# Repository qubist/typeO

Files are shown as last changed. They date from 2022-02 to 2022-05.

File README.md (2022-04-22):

# typeO

e-paper typing software and hardware

## Background

For now, this repo is for collecting relevant information for the prototyping of the typeO using a remarkable and a keyboard.

## Pogo pin connector

The pogo pin connector is in prototype stage. The goal of this device is to provide keyboard access to the reMarkable 2 through the Pogo pins, which have OTG support (unlike the USB C port).

### Software

See [pogo-pin-software.md](/pogo-pin-software.md)

### Hardware

#### Prototype:

https://www.youtube.com/watch?v=7q5tBEi4npA

#### Parts list

- Pogo pin header:
   - Straight: https://www.digikey.com/en/products/detail/821-22-005-10-001101/ED8198-05-ND/1146577?itemSeq=360991255
   - Right-angle: https://www.digikey.com/en/products/detail/mill-max-manufacturing-corp/829-22-005-20-001101/2416226
   - Long: https://www.digikey.com/en/products/detail/mill-max-manufacturing-corp/816-22-005-10-003101/6149711
- USB C breakout: https://www.digikey.com/en/products/detail/4090/1528-2873-ND/9951930?itemSeq=360991872
- 5.1 kOhm resistor
- 1/8in x 1/2in magnets: https://www.kjmagnetics.com/proddetail.asp?prod=D28-N52&cat=168
- tiny dip switch on the PCB for hackability: https://www.digikey.com/en/products/detail/e-switch/KAE01SGGT/3749638

#### Circuit

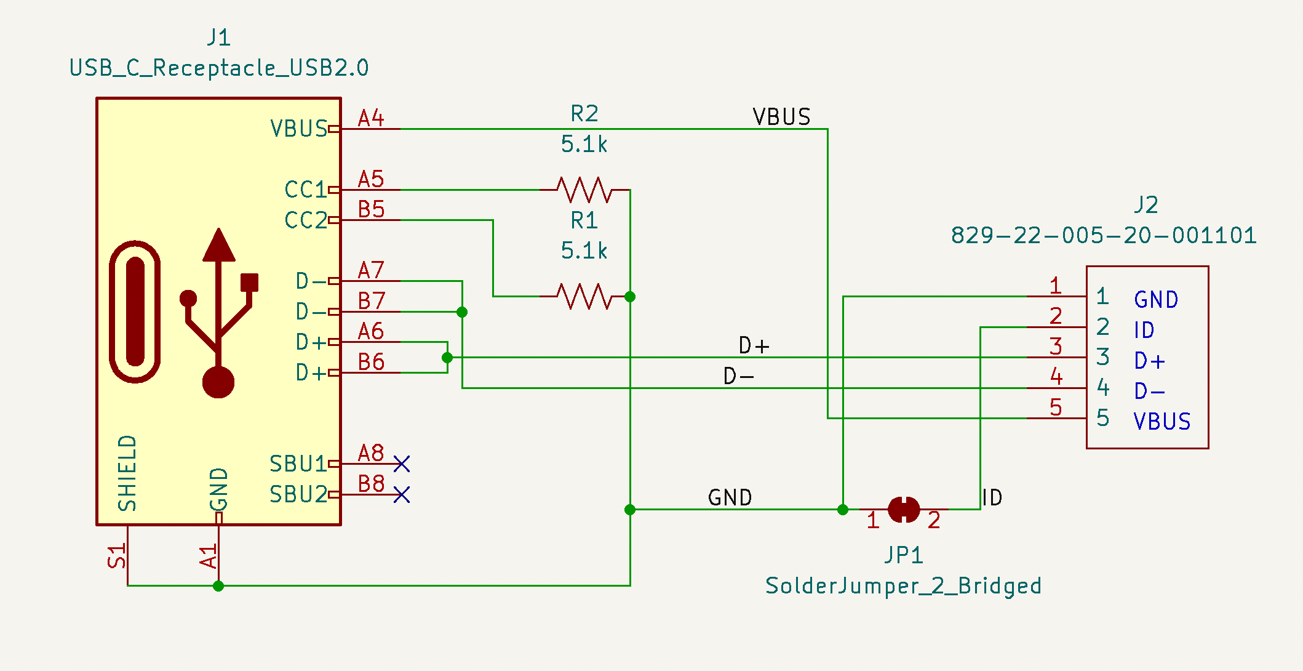
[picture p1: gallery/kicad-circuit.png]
Circuit diagram


Layout image

[Prototype circuit diagram](pcb/prototype_circuit.fzz)

([Reference USB-C pinout](https://electronics.stackexchange.com/questions/291413/usb-c-to-usb-a-pinout/291427))

#### 3D printed part

The 3D printed part holds the magnets and pogo pin headers together and friction fits onto the remarkable. The magnets and flange help it align, and the pins should contact.

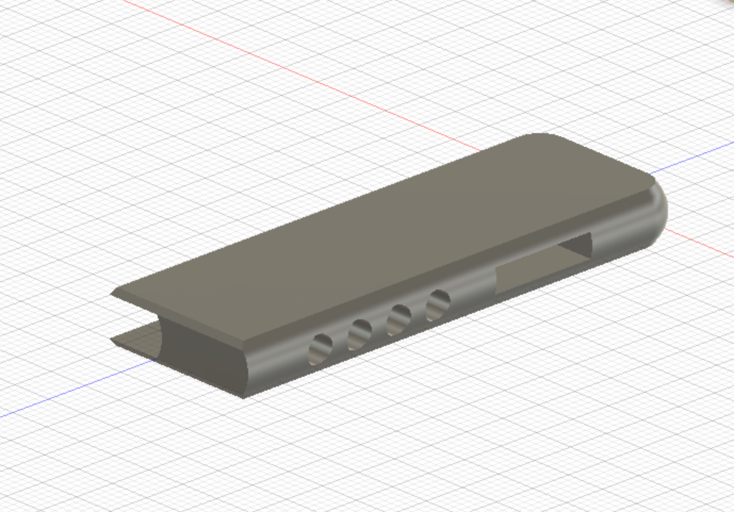
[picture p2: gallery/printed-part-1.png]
printed part 1

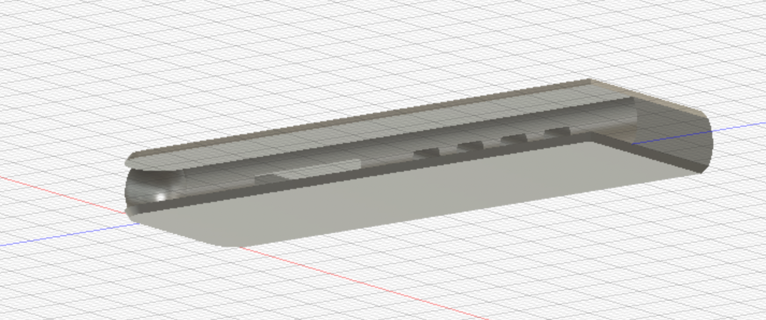
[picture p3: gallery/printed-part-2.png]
printed part 2


## Future

[Feature wishlist](/feature-wishlist.md)

## Other resources

[See also link collection](/sick-links.md)

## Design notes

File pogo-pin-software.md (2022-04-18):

# Pogo behavior and software overview

## Summary

- USB-C port is not powered, works with USB-OTG if externally powered, and requires enabling in software.
- Pogo pins are powered only if USB-C is plugged in, works with USB-OTG if enabled in software, and ID pin grounded.
    - "UPDATE: It seems like you need to have it plugged in to initially work, but after you do the initial fix, it works without plugging it in." (https://github.com/dps/remarkable-keywriter/issues/14#issuecomment-758293624)
- If you wanna use a keyboard, the command `echo 2 > /sys/otgcontrol/control/otg1_controllermode` needs to be run on every reboot to get OTG to work. This can be done automatically. It also seems like it might need to be plugged in to power by USB-C when this command is run for it to work.
    - Here's someone who set up this (or equivalent) command to run automatically: https://benkku.medium.com/the-remarkable-2-tablet-as-a-coding-writing-device-3981570343e2 (search for `Automatically turn on USB-On-the-Go / Host Mode`)

## Always enable OTG keyboard:

Create a file `/usr/local/sbin/disableotg.sh`
```sh
#! /bin/sh
echo 2 > /sys/otgcontrol/control/otg1_controllermode
```
Edit the table of cronjobs: `crontab -e`:
- Add the line disabling OTG-auth recurring at reboot 
  ``` @reboot /usr/local/sbin/diableotg.sh >/dev/null 2>&1```.
Reboot to get it running or run the script yourself.

---

## From the Wiki

The remarkable 2 has two USB port, one USB-C port used for charging and connecting to a PC and a second one exposed on the pogo pins.
The chip used for charging the device (max77818) only supports one VBUS with back power. This bus is connected to the pogo pins, so only this port can be used for USB OTG.

=== Pogo Pins OTG ===

The pogo pinout is:

    (left to right)  
    
    GND, ID, D+, D-, VBUS

With the VBUS closest to the USB-C port. There is a custom linux drivers that controls the USB port dr mode and VBUS power ([[https://github.com/reMarkable/linux/tree/zero-sugar/drivers/misc/rm-otgcontrol]]). The driver monitors the status of the ID pin. If it gets grounded it tries to authenticate the device before changing the port to OTG mode. This authentication is intended to work over a one-wire protocol over the ID port, but is currently unimplemented. As a result the device detection is currently disabled by default ([[https://github.com/reMarkable/linux/commit/e27d817e3c968624f7ae454f9b643157a2d39dab]]).

Luckily there is an unauthenticated mode that can be enabled by writing to sysfs:

    echo 2 > /sys/otgcontrol/control/otg1_controllermode

Now whenever the ID pin is connected to ground, the VBUS supply will be set to OTG mode and the USB mode will change to host. This allows connecting any OTG device by connecting the pogo pins to a Micro-USB connector and using an OTG cable (or creating a custom pogo cable that connects ID to ground).

SOURCE: https://remarkablewiki.com/tech/rm2_otg_pogo

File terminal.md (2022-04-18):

Using Terminal on reMarkable
============================

Prompt
------

### Add battery percentage to the prompt

```
# Show battery percentage in prompt
function battery {
    rot power get batteryLevel
}
PS1='\u@\H:\w ($(battery)%) $ '
```

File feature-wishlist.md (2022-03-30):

# Feature wishlist

## Core features
 
### Hardware

* e-paper screen
* Really lithe casing, Like, a beautiful wooden clamshell kind of thing. Smooth. And grabwanty. Lightweight, durable
* 1 USB-C port for charging and BYO keyboard
* 1 POGO (?) connection for an optional keyboard attachment/case
* Optional keyboard attachment/case
* Open source hardware
* Repairable / hackable
* Expandable storage

### Software

* Fast responsive typing
* Moving cursor around
* Selecting
* Exporting files to a computer
* Open source

## Would be awesome

* warm backlight
* ipx8, I want submerssability, Salty finger beach collaboration
* collaborative editing out in the sun, bust feeling ever
* Vim mode

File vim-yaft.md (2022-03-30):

# Using Vim on Yaft

## Setup

1. Install Yaft
2. Add this to `~/.bashrc`: `export TERM=xterm`

Done.

## Tips

* Hold the escape button on the on-screen keyboard to hide the keyboard
* You can use git to get your vim config from GitHub:
  * `opkg install git`
  * `opkg install git-https`
  *  `git clone ...`
  * `unset LD_PRELOAD` to remove annoying message
* Keep unessesary movement/animation to a minimum
  * Turn of relative line numbers in the gutter

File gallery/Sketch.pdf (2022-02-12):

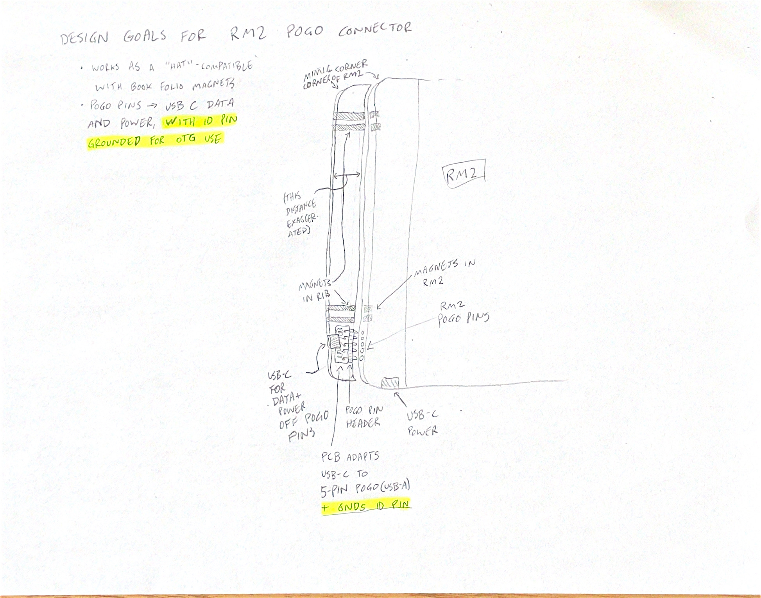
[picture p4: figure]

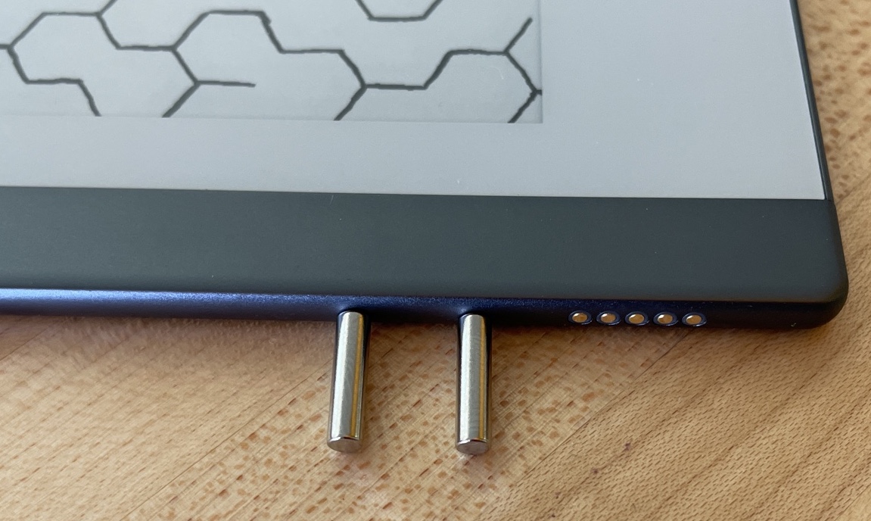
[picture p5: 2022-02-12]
gallery/magnets.jpeg

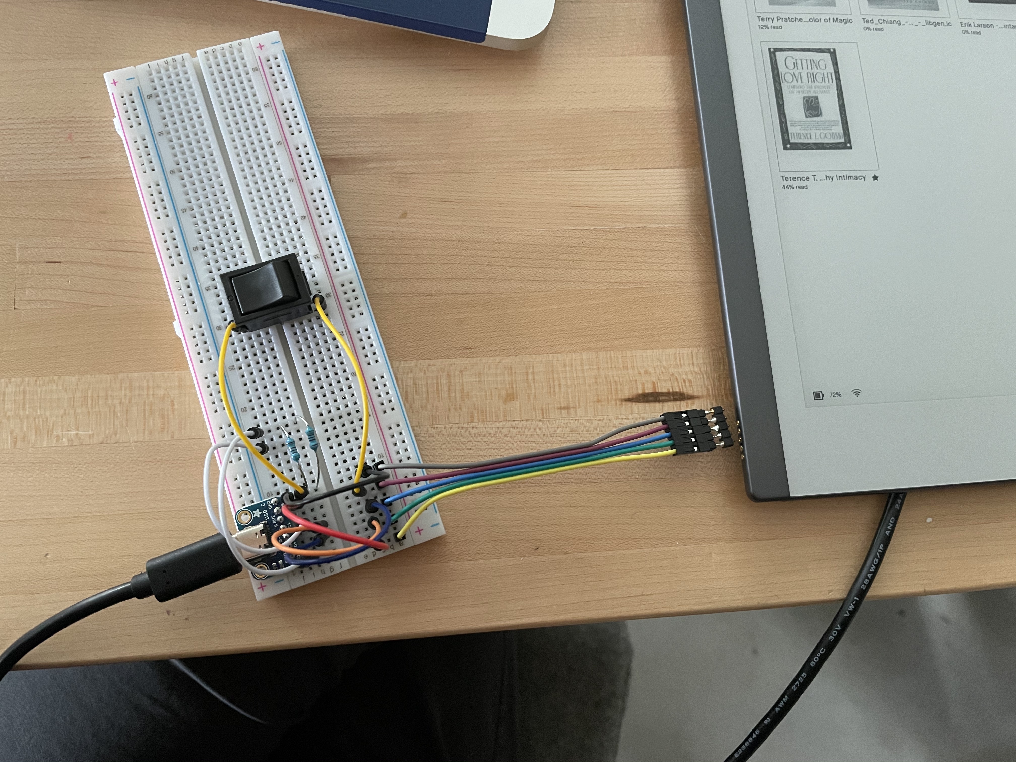
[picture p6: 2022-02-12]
gallery/prototype-circuit.jpg

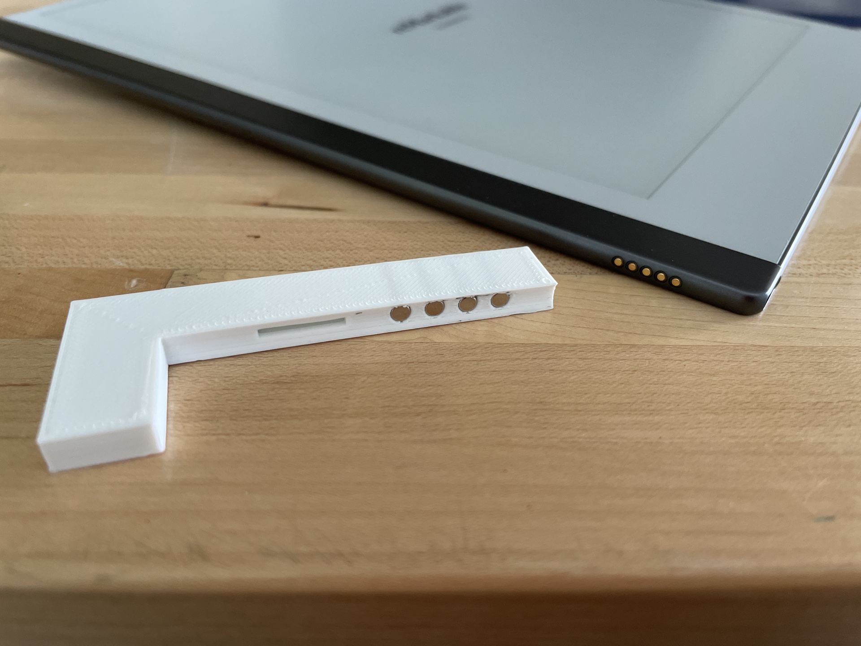
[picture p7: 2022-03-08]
gallery/prototype.jpeg

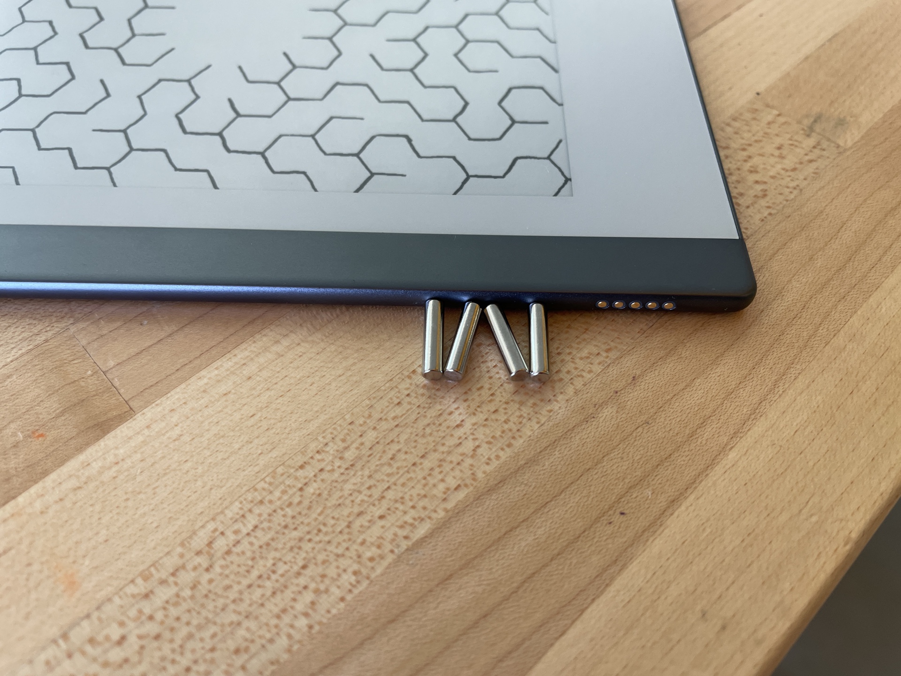
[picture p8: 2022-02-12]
gallery/m-magnet.jpeg

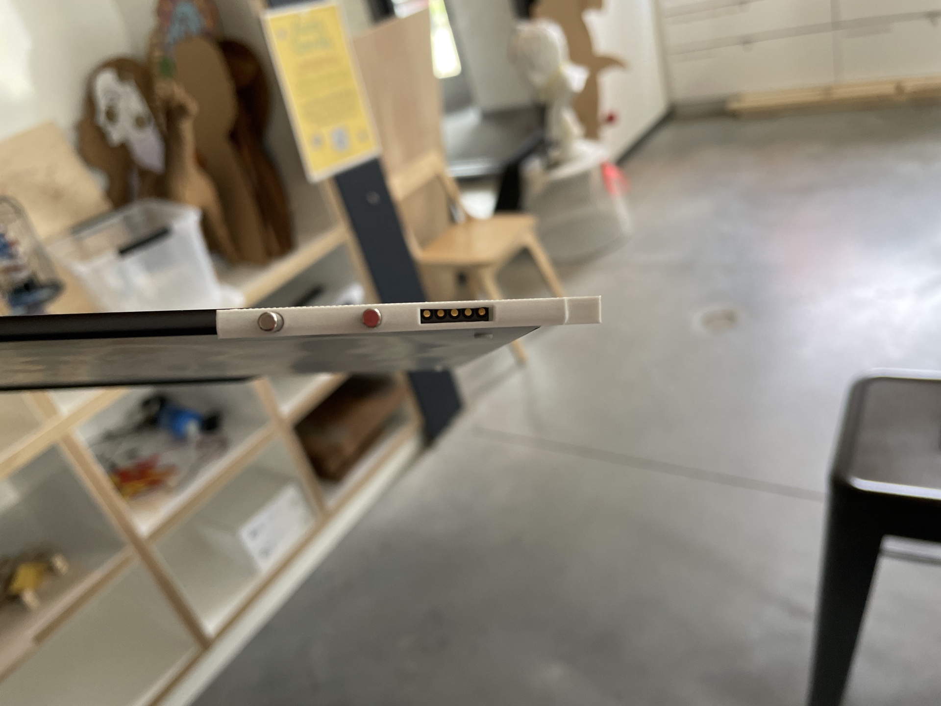
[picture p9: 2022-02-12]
gallery/prototype-side.jpeg

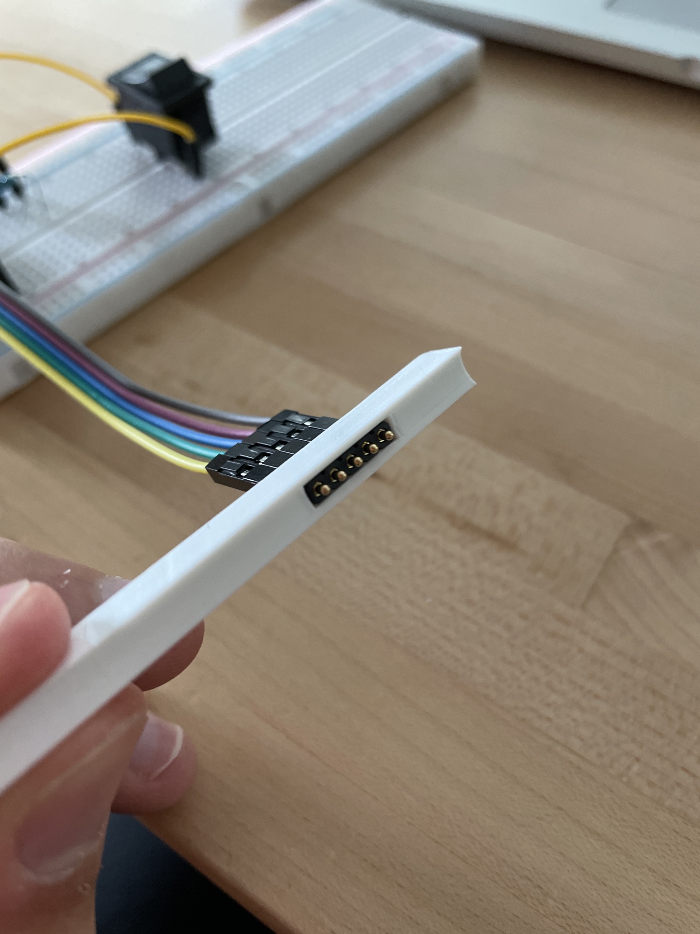
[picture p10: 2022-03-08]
gallery/prototype-pogo-hole.jpeg

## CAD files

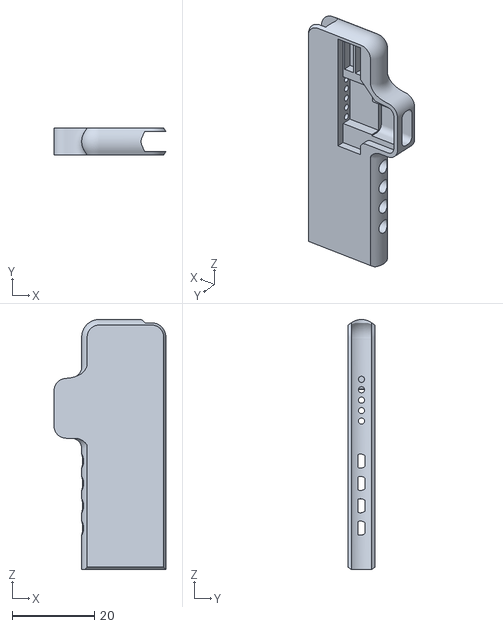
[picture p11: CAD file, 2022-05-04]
J17 Markwardt/3d-model/J17 Markwardt.stl
27.2 x 6.55 x 60.8

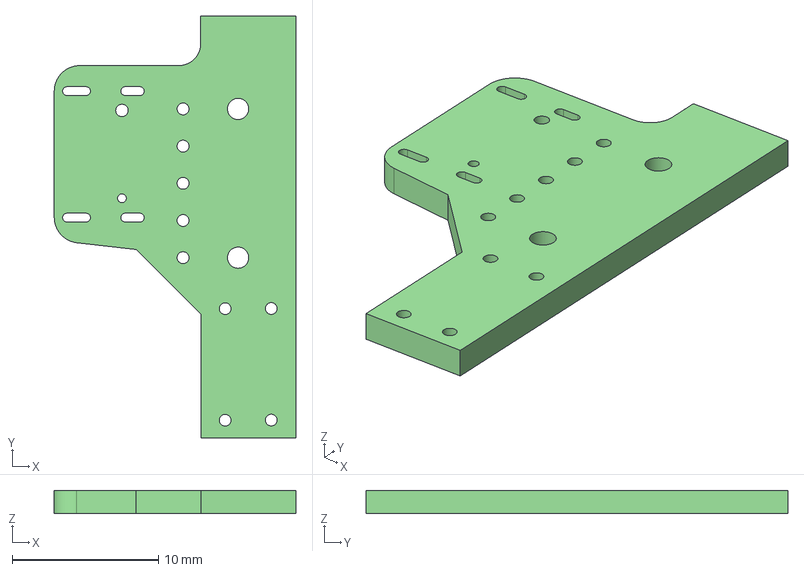
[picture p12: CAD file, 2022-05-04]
J17 Markwardt/pcb/J17-Markwardt-rounded.step
16.5 x 28.8 x 1.60 mm

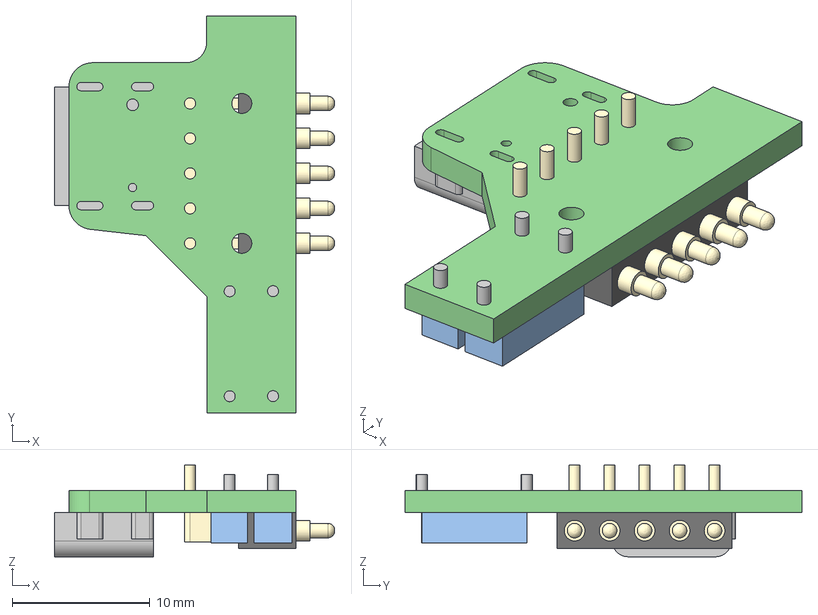
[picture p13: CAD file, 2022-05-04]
J17 Markwardt/3d-model/J17-Markwardt-PCB v8.step
20.4 x 28.8 x 6.65 mm

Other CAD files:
J17 Markwardt/3d-model/J17 Markwardt v8.step
J17 Markwardt/3d-model/J17 Markwardt v8.f3z
J17 Markwardt/3d-model/J17-Markwardt-PCB v8.f3d

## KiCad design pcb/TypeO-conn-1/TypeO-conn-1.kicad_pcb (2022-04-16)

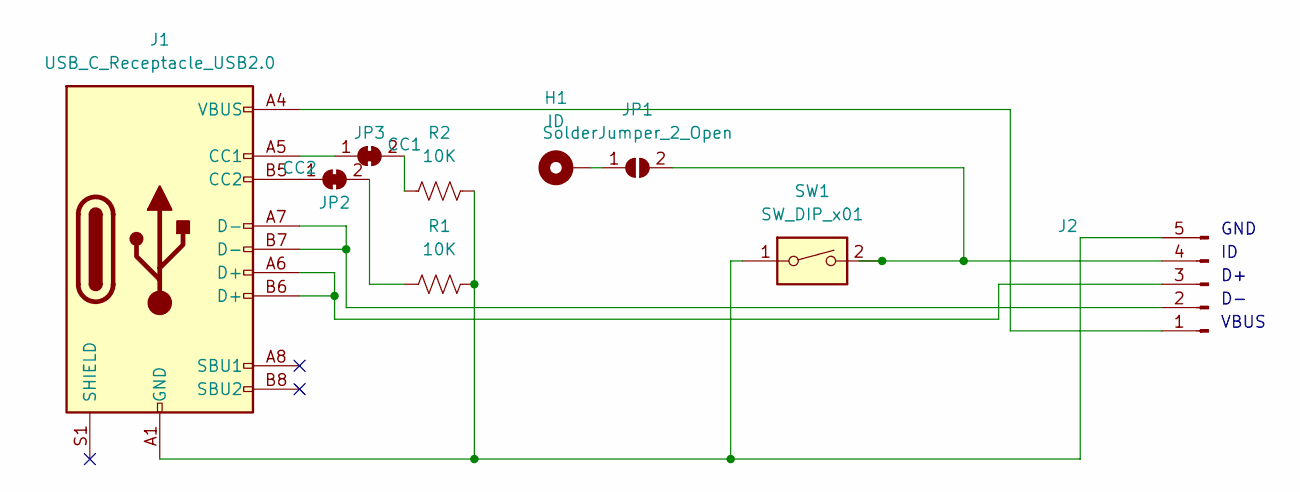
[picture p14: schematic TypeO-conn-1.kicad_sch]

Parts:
H1: ID; SolderWire-0.1sqmm_1x01_D0.4mm_OD1mm
J1: USB_C_Receptacle_USB2.0; USB_C_Receptacle_JAE_DX07S016JA1R1500
J2: (no value)
JP1: SolderJumper_2_Open; SolderJumper-2_P1.3mm_Open_TrianglePad1.0x1.5mm
JP2: CC2; SolderJumper-2_P1.3mm_Bridged_RoundedPad1.0x1.5mm
JP3: CC1; SolderJumper-2_P1.3mm_Bridged_RoundedPad1.0x1.5mm
R1, R2: 10K; R_Axial_DIN0207_L6.3mm_D2.5mm_P7.62mm_Horizontal
SW1: SW_DIP_x01; SW_DIP_SPSTx01_Slide_Omron_A6S-110x_W8.9mm_P2.54mm

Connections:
unnamed: H1.1, JP1.1 (A)
unnamed: J1.A1 (GND), J1.A12 (GND), J1.B1 (GND), J1.B12 (GND), J2.5, R1.1, R2.1, SW1.1
unnamed: J1.A4 (VBUS), J1.A9 (VBUS), J1.B4 (VBUS), J1.B9 (VBUS), J2.1
unnamed: J1.A5 (CC1), JP3.1 (A)
unnamed: J1.A6 (D+), J1.B6 (D+), J2.3
unnamed: J1.A7 (D-), J1.B7 (D-), J2.2
unnamed: J1.B5 (CC2), JP2.1 (A)
unnamed: J2.4, JP1.2 (B), SW1.2
unnamed: JP2.2 (B), R1.2
unnamed: JP3.2 (B), R2.2

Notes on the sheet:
VBUS
GND

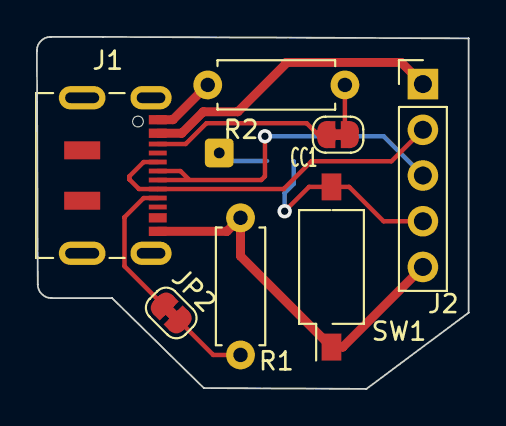
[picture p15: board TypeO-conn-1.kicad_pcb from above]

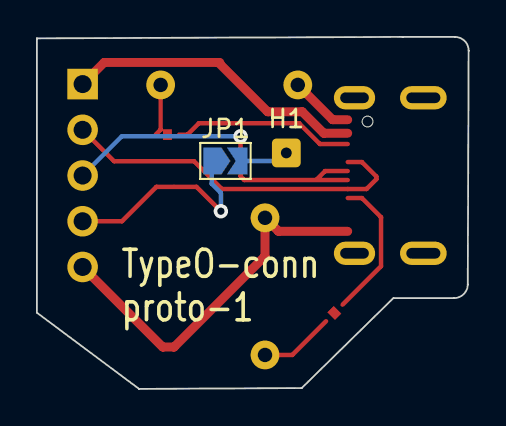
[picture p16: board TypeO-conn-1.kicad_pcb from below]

Board: 2 copper layers, 24.0 x 19.6 mm, 9 parts (2 on the bottom side), 10 nets.

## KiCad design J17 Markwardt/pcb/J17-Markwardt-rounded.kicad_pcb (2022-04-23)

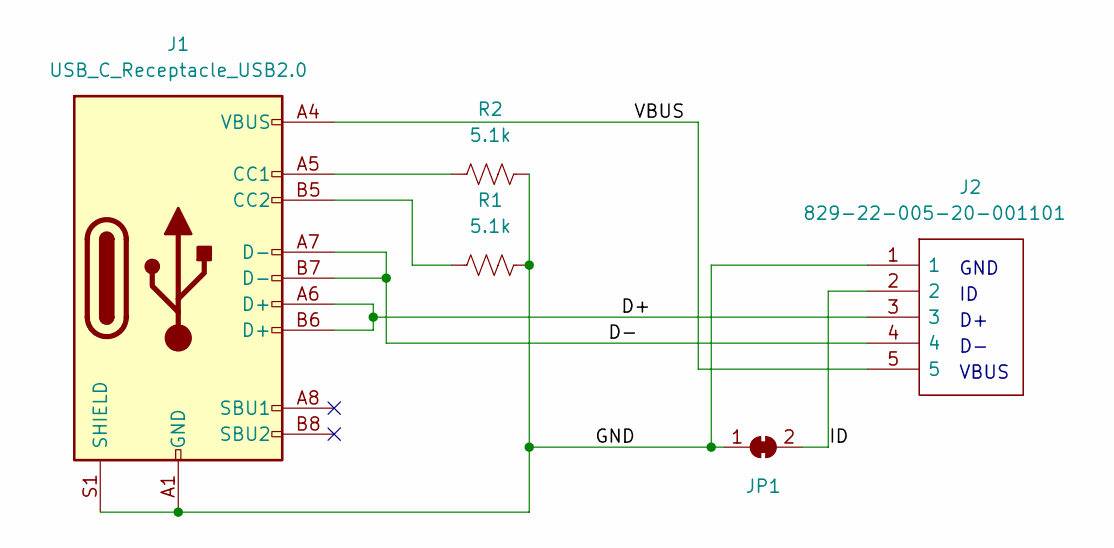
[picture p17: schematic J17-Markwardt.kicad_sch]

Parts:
J1: USB_C_Receptacle_USB2.0; USB_C_Receptacle_JAE_DX07S016JA1R1500
J2: 829-22-005-20-001101; 8292200520001101; Manufacturer_Part_Number 829-22-005-20-001101; Mouser Part Number 575-8292200520
JP1: (no value)
R1, R2: 5.1k; R_Axial_DIN0207_L6.3mm_D2.5mm_P7.62mm_Horizontal

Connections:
/D+: J1.A6 (D+), J1.B6 (D+), J2.3
/D-: J1.A7 (D-), J1.B7 (D-), J2.4
/GND: J1.A1 (GND), J1.A12 (GND), J1.B1 (GND), J1.B12 (GND), J1.S1 (SHIELD), J2.1, JP1.1 (A), R1.1, R2.1
/ID: J2.2, JP1.2 (B)
/VBUS: J1.A4 (VBUS), J1.A9 (VBUS), J1.B4 (VBUS), J1.B9 (VBUS), J2.5
unnamed: J1.A5 (CC1), R2.2
unnamed: J1.B5 (CC2), R1.2

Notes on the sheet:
VBUS
GND

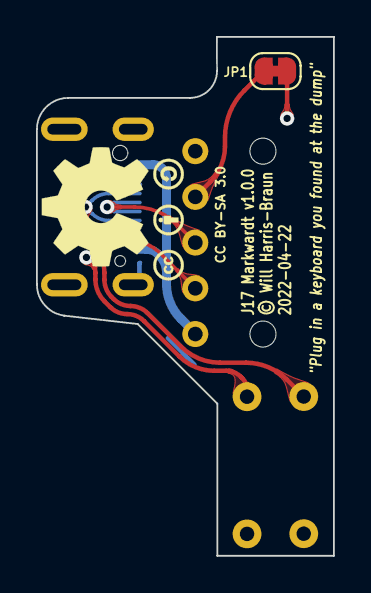
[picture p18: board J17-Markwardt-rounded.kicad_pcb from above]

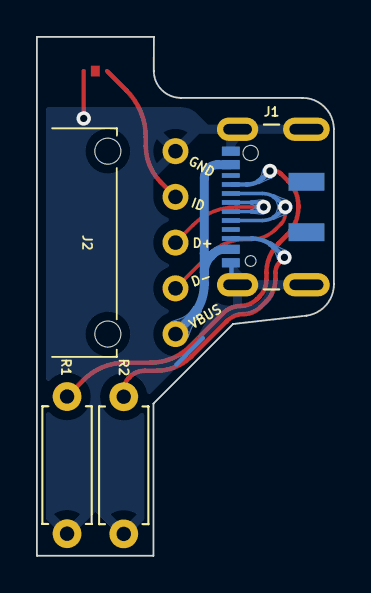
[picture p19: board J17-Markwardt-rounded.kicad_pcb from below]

Board: 2 copper layers, 16.5 x 28.8 mm, 5 parts (3 on the bottom side), 7 nets.

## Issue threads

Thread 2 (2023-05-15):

Markwadt printing

ayakael, 2023-05-15:
I'm very interested in printing my own Markwadt case with pcb as to be able to have keyboard support on my rM2. You had mentionned that you were still waiting on the PCB to come in in may 2022. What service did you use to print your PCB?

Many thanks!

ayakael, 2023-05-15:
Did so more research on my offerings. I have a few questions for you:

* **PCB**: I've found OSH Park for PCB printing, so I shouldn't have any issues there.
* **Casing**: My local 3D printing shop offers many differents kind of materials for the casing. What material would you recommend (SLS, SLA, PDL, POLYJET, and DMLS)?
* **Magnets**: Where do you source these, as they are different than what you point to in README
* **USB-C / Pogo**: Could you share your digikey links to these?
* **Recovery**: Will this work for recovery purposes? I know for a fact that pogo -> microUSB works fine, but I don't enough about USB-C design to know if what you do with ID pin will work.

After succesfully building this, I'd be happy to send a PR with an up-to-date README.

ayakael, 2023-05-15:
Amazing what more research will do!

* **PCB**: Resolved
* **Casing**: Not resolved, still wondering what meterials would be best
* **Magnets**: Resolved, looking at an [image of your prototype that I found](https://cdn.discordapp.com/attachments/830092059578466322/975894856385835038/signal-2022-05-03-230014_001.jpeg), it looks like you use the same magnets
* ** USB-C / Pogo**: Resolved, found the info in your kicad file. For prosterity: [pogo](https://www.digikey.ca/en/products/detail/mill-max-manufacturing-corp/829-22-005-20-001101/2416226), [usb-c](https://www.digikey.ca/en/products/detail/jae-electronics/DX07S016JA1R1500/11585731), [5.1k resistor - needs 2](https://www.digikey.ca/en/products/detail/yageo/CFR-25JB-52-5K1/2236), [switch](https://www.digikey.ca/en/products/detail/e-switch/KAE01SGGT/3749638)
* ** Recovery **: Not resolved, I see that the switch is used to allow shorting ID to GND. If memory serves, grounding ID turns the USB port into host mode, right? Thus, for recovery, ID should not be shorted to ground as to initialize USB as slave.

Time to order the parts and PCB!

qubist, 2023-05-31:
Hey sorry, I'm just seeing this.

* **Casing:** I used PLA.
* **Magnets:** I think the link in the existing readme is correct: https://www.kjmagnetics.com/proddetail.asp?prod=D28-N52&cat=168 Help me understand how they're different than those?
* **Recovery:** Exactly right, that's why the switch is there.

If it's not too late and you don't want to order PCBs I can send you some, I have a bunch now but am just distracted from this project. Can also send other components.

MorvinBear, 2023-06-12:
Antoine,

PLeasure to meet you, and to see this thread alive. I have another project
that I'd love to chat with you about that I'm 94% certain you're going to
be like, "oh, whoa, yeah!" or some variation of that about. My number's +1
561 307 7718.

Best,
Bear

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

aflusche, 2024-02-10:
> Time to order the parts and PCB!

Did you build this?

I had version 13 of @qubist's connector printed, and I'm having a check of a time getting everything to work. Even without the 3d printed part, I can't get a reliable connection between my pogo pins and the RM2.

qubist, 2024-02-14:
Hi @aflusche,

I've built one that works, but not of the current iteration that's posted here. It used an older clunkier design of the PCB and 3D-printed part but everything was electronically and magnetically the same. And I had pretty good luck using it. I coded for a whole day using the RM2 as a display with my ZSA Moonlander keyboard.

Can you show version 13 that you're talking about? Did you go back in the history of this repo to find it? And what's the exact problem you're encountering? Pics would help.

aflusche, 2024-02-15:
Thanks @qubist !

I ended up abandoning the pogo attachment idea because I just couldn't get it work reliably. I'm using the USB C port to connect like [this](https://github.com/FunkyFab/pageturner) project. (I'm making a page turner pedal for sheet music.)

Here was my initial pogo connector plan. I slightly modified your 3d design to accommodate another connector on the opposite side as the RM. I was going to have another pogo connector that would magnet up to the top portion of this, then lead down to my foot pedal.

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

I ended up abandoning that approach due to my poor soldering skills to connect the two pogo pin sets that closely.

The next plan was to just wire directly to the pins that touch the RM and shove it all in the plastic piece that magnets to the RM:

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

I could _sometimes_ get the RM to see my input, but not often. The _power_ pin would work, so my input device would be getting juice from the RM. But the RM wouldn't respond to my input.

The connection also seemed pretty unsteady. Ex: when I _could_ get it connect, it was often by using manual pressure on the 3d piece to hold it in place.

Your work is awesome and inspiring! Hopefully my experience will help others. And maybe I was just making a stupid mistake... I plan to post my final working pedal when it's finished; hopefully next week.

qubist, 2024-02-15:
Got it, thanks for sharing your progress!

The newest version of the 3D printed part I designed has these kind of wings that grip the RM2 from the front and back that helped a lot with the connection. I see the one you printed was an older version without that, maybe that contributed to it not having a reliable connection.

Here's a picture of a prototype in action:

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

Notice the the teal part.

Good luck with your page turner!

aflusche, 2024-02-15:
Very cool! Yes, I saw the teal updated design when I went looking for solutions to my poor connectivity. I don't know how I missed that before I ordered my 3D print. :/

Don't worry about the STL for now, but thanks for the offer! I think my new version is going to work better for my purposes. I'm running a battery test right now to make sure my lipo rechargeable battery has enough battery life to be reliable.

The world is an amazing place: multiple people who've never met can collaborate on a project and literally produce physical parts that are figments of a person's imagination.

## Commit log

2022-02-13 Add printed part info
2022-03-30 Add circuit
    [TypeO-conn-1.kicad_pcb, TypeO-conn-1.kicad_sch]
2022-03-30 Update PCB
    [TypeO-conn-1.kicad_pcb]
2022-03-30 Update PCB to add jumpers
    [TypeO-conn-1.kicad_pcb, TypeO-conn-1.kicad_sch]
2022-04-19 Change naming scheme for PCB design
    Will start using git tags to mark versions and just have one file. Git
    will save version history.
    [typeO-conn.kicad_pcb, typeO-conn.kicad_sch]
2022-04-19 Add new Pogo pin links
2022-04-19 Start work on typeO-conn v2
    [typeO-conn.kicad_pcb, typeO-conn.kicad_sch]
2022-04-19 Prettify circuit diagram and add to Readme
    [typeO-conn.kicad_sch]
2022-04-19 Change resistor values
    [typeO-conn.kicad_pcb, typeO-conn.kicad_sch]
2022-04-19 Update circuit diagram
2022-04-19 Start ignoring KiCad backups
2022-04-22 Rearrange and update silkscreen
    [prototype_circuit.fzz, typeO-conn.kicad_pcb, typeO-conn.kicad_sch]
2022-04-23 Add final edge cuts
    [typeO-conn.kicad_pcb]
2022-04-23 Add rounded, updated date
    [typeO-conn-rounded.kicad_pcb]
2022-04-23 Rename connector to J17 Markwardt
    [J17-Markwardt-rounded.kicad_pcb, J17-Markwardt.kicad_pcb, J17-Markwardt.kicad_sch]
2022-04-23 Update board a lil
2022-05-04 Add new Markwardt case with space for PCB
    [J17 Markwardt v8.f3z, J17 Markwardt v8.step, J17 Markwardt.stl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]

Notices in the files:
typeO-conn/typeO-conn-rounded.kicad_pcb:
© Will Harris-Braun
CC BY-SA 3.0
